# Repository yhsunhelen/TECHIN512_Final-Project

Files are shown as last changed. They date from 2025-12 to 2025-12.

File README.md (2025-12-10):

# Zombie Shooter – 90s-Style Handheld Reaction Game

A 90s-style handheld electronic game built with the Seeed Studio **XIAO ESP32C3** and **CircuitPython**.  
The game mixes fast reactions, motion aiming, sound input, a touch-shield, and zombies.

> Platform: XIAO ESP32C3 + CircuitPython  
> Display: SSD1306 128×64 OLED  
> Inputs: ADXL345 accelerometer, rotary encoder, trigger button, capacitive touch pad, sound sensor  
> Outputs: NeoPixel RGB LED, piezo buzzer, vibration motor  
> Power: LiPo battery + on/off switch

---

## How to Play

### 1. Power-On & Splash Screen

When the device is turned on:

- An animated story / splash screen is shown by `ui.show_boot_animation(display, btn)`.
- This splash animation plays **only on power-up**, not when restarting after Game Over.

After the splash, the game enters the **main menu**.

---

## Menus & Difficulty

The **rotary encoder** is used only outside of gameplay:

- Rotate to move between menu items.
- Press the encoder button to confirm.

Main menu (`menu.main_menu`):

- `PLAY` – start a new game.
- `SCORES` – view the high-score leaderboard.
- `SETTINGS` – change difficulty.

### Difficulty Settings

From `menu.difficulty_menu` the player can choose:

- `EASY`
- `NORMAL`
- `DIFFICULT`

The selected difficulty affects:

- How many zombies can be on screen at once.
- How quickly zombies spawn.
- How long each zombie stays alive before it disappears and may damage the player.

For each difficulty, `ZOMBIE_LIFETIME_TABLE` defines the lifetime for levels 1–10  
(shorter lifetimes at higher levels ⇒ harder).

---

## One-Time Tutorial (3 Parts)

The tutorial runs **once** after power-on, the first time the player chooses `PLAY`:

```python
tutorial_shown = False
...
if not tutorial_shown:
    show_tutorial(display)
    tutorial_shown = True
```

`show_tutorial(display)` contains 3 parts:

### Tutorial 1/3 – Shooting Z

- **Part 1-A (text)**: Explains that you tilt to move the `+` crosshair and press the button to shoot `Z`.
- **Part 1-B (practice)**:
  - A `+` crosshair and one `Z` appear on a clean screen.
  - The accelerometer (ADXL345) is read and filtered with an exponential moving average:

    ```python
    local_xf = local_alpha * x + (1 - local_alpha) * local_xf
    local_yf = local_alpha * y + (1 - local_alpha) * local_yf
    ```

  - Filtered X/Y are mapped to screen coordinates; the crosshair follows your tilt.
  - Pressing the trigger button checks if the crosshair is near the `Z`:
    - Close enough → `hit_effect()` (NeoPixel green, beep, vibration).
    - Miss → `miss_effect()` (NeoPixel red, different beep).

### Tutorial 2/3 – S & Sound Sensor

- **Part 2-A (text)**: Explains that when `S` appears you use **sound**, not aiming.
- **Part 2-B (practice)**:
  - A big `S` is shown on screen.
  - The digital sound sensor on D3 is read:
    - Quiet = 1, loud spike = 0
  - A transition `1 → 0` while the buzzer is not active triggers:
    - A beep and `hit_effect()` — simulating the destruction of `S` by a clap or shout.

### Tutorial 3/3 – T & Shield Touch

- **Part 3-A (text)**: Explains that when `T` appears, you touch the left pad to raise the shield.
- **Part 3-B (practice)**:
  - A simple scene with a `T` and text.
  - Touching the **left capacitive pad** (D2) long enough:
    - Calls `hit_effect()` and removes the T in the tutorial.
    - Demonstrates the “shield vs T” mechanic.

---

## Fingerprint Unlock (Touch Pad)

After the tutorial (if enabled by `FINGERPRINT_UNLOCK_ENABLED = True`),  
a “fingerprint unlock” screen appears before entering the real game:

```python
if FINGERPRINT_UNLOCK_ENABLED:
    fingerprint_unlock()
    display.root_group = main_group
```

`fingerprint_unlock()`:

- Shows text:

  > Know: put your finger  
  > on the left touch pad  
  > when it glows green,  
  > to unlock your weapon.

- Sets the NeoPixel to a **dim green** `(0, 80, 0)` while waiting.
- When the player touches the pad and holds it for `REQUIRED_HOLD = 0.5s`:
  - The text changes to:

    > Weapon unlocked!  
    > Welcome back,  
    > Zombie Hunter.  
    > Press BTN to start

  - NeoPixel changes to **bright green** `(0, 255, 0)`.
- The player presses the button to continue to the main game.

---

## Game Structure

### Levels & Timing

- Each run contains **10 levels** per difficulty:

  ```python
  MAX_LEVEL = 10
  GAME_DURATION = 10.0  # seconds per level
  ```

- Each level lasts exactly **10 seconds**.
- If the player is still alive when the level timer reaches 0:
  - If current level < 10 → advance to the next level.
  - If current level == 10 → the player has cleared all levels.

During gameplay the top of the OLED shows:

- `S:<score>` – current score
- `HP:<value>` – player health (max 3)
- `T:<seconds>` – remaining time in the current level

The bottom shows difficulty and level:

- `E L1`, `N L4`, `D L7`, etc.

### HP and Damage

- `MAX_HP = 3`
- When a zombie’s personal lifetime expires, `update_zombies()` checks the shield:
  - If shield **not** active → HP decreases by 1.
  - The zombie is removed.
- When HP decreases:
  - The HP label is updated.
  - `damage_effect()` plays: NeoPixel orange flash + vibration + low-pitch beep.
- If HP reaches 0:
  - `hp_reached_zero = True`
  - `running = False` → end of the game.

---

## Zombies & Player Moves

There are three zombie types:

- **Z** – standard zombie (shoot with crosshair + button)
- **S** – sound zombie (destroy with sound)
- **T** – shield zombie (destroy with touch shield)

Spawn logic (`spawn_zombie`) selects Z/S/T probabilities based on:

- Difficulty (`EASY`, `NORMAL`, `DIFFICULT`)
- Current level index

### In-Game Controls

1. **Aim with Tilt (ADXL345)**  
   - Crosshair `+` is always controlled by the accelerometer:

     ```python
     x_f = alpha * x + (1 - alpha) * x_f
     y_f = alpha * y + (1 - alpha) * y_f
     px = map_to_range(x_f, MIN_X, MAX_X, SCREEN_X_MIN, SCREEN_X_MAX)
     py = map_to_range(-y_f, MIN_Y, MAX_Y, SCREEN_Y_MIN, SCREEN_Y_MAX)
     ```

   - `alpha = 0.2` for smooth movement (low-pass filter).
   - Filtered values are mapped/clamped into the screen area and set as `crosshair.x` / `crosshair.y`.

2. **Shoot (Trigger Button on D9)**  
   - The trigger button is debounced by `update_button()`.
   - When pressed and **shield is not active** (`can_shoot = True`):
     - `fired_any_shot = True`
     - `muzzle_flash()` is called (NeoPixel white flash).
     - `find_hit_zombie(px, py)` tests if the crosshair overlaps a `Z`.
       - If a `Z` is found:
         - It is removed.
         - Score increments, label updated.
         - `hit_effect()` plays (green flashes, beep, vibration).
       - If nothing / `S` / `T` is hit:
         - `miss_effect()` plays (red flash, miss sound).

   - If the button is pressed while the shield is up (`can_shoot = False`):
     - The text area briefly shows `SHIELD UP!` and no shot is fired.

3. **Sound Move (Sound Sensor on D3, for S)**  
   - Each loop reads the digital sound sensor:
     - Quiet: `sound_sensor.value == 1`
     - Loud spike: `sound_sensor.value == 0`
   - A `1 → 0` edge is detected:

     ```python
     sound_edge = (sound_last_state and (not cur_sound))
     ```

   - If `sound_edge` and the buzzer is not playing:
     - One **S zombie** on screen is removed (loop breaks after the first).
     - Score increases and `hit_effect()` is called.

4. **Shield Move (Touch Pad on D2, for T)**  
   - `shield_active = bool(touch.value)`; when true:
     - `can_shoot = False` (cannot fire).
     - A loop walks through `zombies[:]`:
       - On the first alive `T` zombie:
         - It is removed.
         - Score increases.
         - `hit_effect()` plays.
         - Loop breaks → **one T per shield activation**.
   - When shield is active and a zombie lifetime ends:
     - The player does **not** lose HP (see `update_zombies`).

These four moves — **tilt to aim**, **shoot button**, **sound**, and **shield touch** — are the player’s actual actions.

---

## Scoring & Leaderboard

### Score

- Each destroyed zombie (Z/S/T) adds 1 point.
- Score label: `S:<value>` is updated whenever `game_score` changes.
- Final score is shown on the Game Over or victory/clear screen.

### Game Over & Clear

At the end of the `while running` loop:

- If the player survived all 10 levels → `cleared_all_levels = True`.
- If HP reached 0 → `hp_reached_zero = True`.

Then:

1. **Boss Easter Egg (Clear All Levels)**  
   If `cleared_all_levels` is `True`:

   ```python
   easter2.show_boss_easter(display, btn, buzzer)
   ```

   - Special animation of running through zombies and story text.
   - Buzzer sound effects during this sequence.

2. **No-Shot Easter Egg**  
   After the game:

   ```python
   if not fired_any_shot:
       easter.show_no_shot(display, btn, buzzer)
       display.root_group = main_group
       continue
   ```

   - If the player never fired a bullet in the whole run,  
     a “peaceful player / no bullet fired” easter egg screen is shown instead of the normal Game Over.

3. **Normal Game Over Screen**

   If the run was not a no-shot easter egg:

   ```python
   show_game_over(display, game_score, hp_reached_zero)
   ```

   - Displays:
     - `"YOU DIED"` if HP reached zero, or `"TIME UP"` otherwise.
     - `Score: <value>`
     - `BTN: CONTINUE`

4. **High Score Entry & Leaderboard**

   - Uses `score.py`:

     ```python
     if score.can_enter_leaderboard(game_score):
         player_name = NameInput.enter_name(display, encoder, btn, max_len=3)
         score.add_score(player_name, game_score)
     ```

   - `NameInput.enter_name` lets the player use the rotary encoder to select 3-character initials.
   - Scores are stored in `scores.json` on the internal flash (no SD card).
   - `show_leaderboard(display)` then shows the high score list:
     - Up to several entries with rank, initials, and score.
     - Encoder rotates to scroll if more entries exist.
     - Press button to go back to main menu.

The player can start a new game from the menu **without power-cycling**.

---

## NeoPixel Behavior

A single NeoPixel on **D10** is used for clear color-coded feedback:

- **Unlock Tutorial / Fingerprint Screen**
  - Dim green `(0, 80, 0)` while waiting for touch.
  - Bright green `(0, 255, 0)` when the weapon is successfully unlocked.

- **Shield Tutorial (Part 3 practice)**  
  - When the player successfully clears the T in the tutorial, a green flash + `hit_effect()` is used.

- **Muzzle Flash (Shooting) – `muzzle_flash()`**
  - Brief **white** `(255, 255, 255)` flash when the trigger is pressed.

- **Hit Effect – `hit_effect()`**
  - Two short **green** `(0, 255, 0)` flashes.
  - Vibration motor on D8 pulses.
  - A high-pitch beep plays.

- **Miss Effect – `miss_effect()`**
  - Single **red** `(255, 0, 0)` flash.
  - Medium-pitch miss beep.

- **Damage Effect – `damage_effect()`**
  - **Orange** `(255, 50, 0)` flash.
  - Vibration pulse and deeper tone.

After each effect, the pixel is set back to `(0, 0, 0)` (off).

> The NeoPixel uses multiple distinct colors (dim & bright green, white, red, orange),  
> which clearly satisfies the requirement to use more than one color.

---

## Audio & Vibration

### Buzzer (D7, PWM)

The buzzer is driven by `pwmio.PWMOut` on D7:

- `play_beep(freq, duration, volume)`:
  - Sets `buzzer_active = True` during playback to prevent the sound sensor from falsely triggering.
- **Game start sound**:

  ```python
  def game_start_sound():
      play_beep(500, 0.08)
      play_beep(750, 0.08)
      play_beep(1000, 0.12)
  ```

  Called at the beginning of each game.

- Different tones for:
  - Hit (`hit_effect`)
  - Miss (`miss_effect`)
  - Damage (`damage_effect`)
  - Tutorial confirmations and easter egg scenes.

### Vibration Motor (D8)

- Controlled by a digital output on D8:
  - Pulses during `hit_effect()` and `damage_effect()` to give haptic feedback.

---

## Sensors & Filtering

### ADXL345 Accelerometer

- Connected via I2C with the OLED.
- Used only for **aiming** the crosshair.
- The code uses an exponential moving average:

  ```python
  alpha = 0.2
  x_f = alpha * x + (1 - alpha) * x_f
  y_f = alpha * y + (1 - alpha) * y_f
  ```

- Then maps the smoothed values into a limited range `[MIN_X, MAX_X]` / `[MIN_Y, MAX_Y]` and finally into OLED pixel coordinates `[SCREEN_X_MIN, SCREEN_X_MAX]` / `[SCREEN_Y_MIN, SCREEN_Y_MAX]`.

This provides proper filtering for the accelerometer as required.

### Sound Sensor (D3)

- Digital input with pull-up:
  - Quiet: `1`
  - Loud spike: `0`
- A `1 → 0` transition triggers:
  - Tutorial Part 2 success.
  - In-game S-zombie kill (one `S` per edge).

### Touch Pad (D2)

- Digital input with pull-down.
- Used for:
  - Fingerprint unlock.
  - T-zombie shield move during gameplay.

### Trigger Button (D9) & Encoder

- Trigger button:
  - Debounced by `update_button()` for reliable edge detection.
- Rotary encoder:
  - Implemented by `RotaryEncoder` class in `rotary_encoder.py`.
  - Used for menus and name/initial selection.

---

## Files & Project Structure

Suggested repository structure:

```text
.
├── codfiles/
│   ├── code.py             # Main game loop, state machine, input handling
│   ├── ui.py               # Splash screen, story pages, UI screens
│   ├── menu.py             # Main menu and difficulty selection
│   ├── easter1.py          # First easter egg (optional/mini event)
│   ├── easter2.py          # Boss / major easter egg animation and story
│   ├── scores.py           # Scoring and high score storage (scores.json)
│   ├── name_input.py       # Rotary encoder-based name/initial input
│   ├── rotary_encoder.py   # Rotary encoder helper class / driver
│
├── lib/                    # CircuitPython libraries used by the game
│   ├── adafruit_display_text/
│   ├── adafruit_displayio_ssd1306.mpy
│   ├── adafruit_adxl34x.mpy
│   ├── i2cdisplaybus.mpy
│   ├── neopixel.mpy
│
├── Documentation/
│   ├── System Block Diagram.png  # system block diagram
│   └── Final Circuit Diagrams.pdf # wiring diagram / schematic
│
├── enclosure/
│   ├── 20251207_1.stl
│   ├── 20251207_2.stl
│
└── README.md

To run on the actual device, copy the contents of `code/` and `lib/` to the CIRCUITPY drive (with `code.py` at the root).

---
```
## Hardware & Enclosure Summary

- Seeed Studio **XIAO ESP32C3** microcontroller  
- **SSD1306 128×64 OLED** on I2C (shared with ADXL345)  
- **ADXL345 accelerometer** (I2C)  
- **Rotary encoder + push button** for menus & name input  
- **Trigger button** (D9) for shooting  
- **Capacitive touch pad** (D2) for shield/unlock  
- **Digital sound sensor** (D3) for S-zombie move  
- **NeoPixel RGB LED** (D10)  
- **Piezo buzzer** on D7 (PWM)  
- **Vibration motor** on D8  
- **LiPo battery** and **on/off switch**  
- All mounted on perfboard or a PCB using **female headers** so modules are removable.

The enclosure:

- Securely holds all electronics.
- Exposes:
  - USB-C port for the XIAO.
  - On/off switch.
  - OLED window.
  - Openings for trigger, encoder, and touch pad.
- Has a removable lid/side so the electronics can be accessed easily.
- Any 3D-printed parts are **not yellow**, following the project constraints.

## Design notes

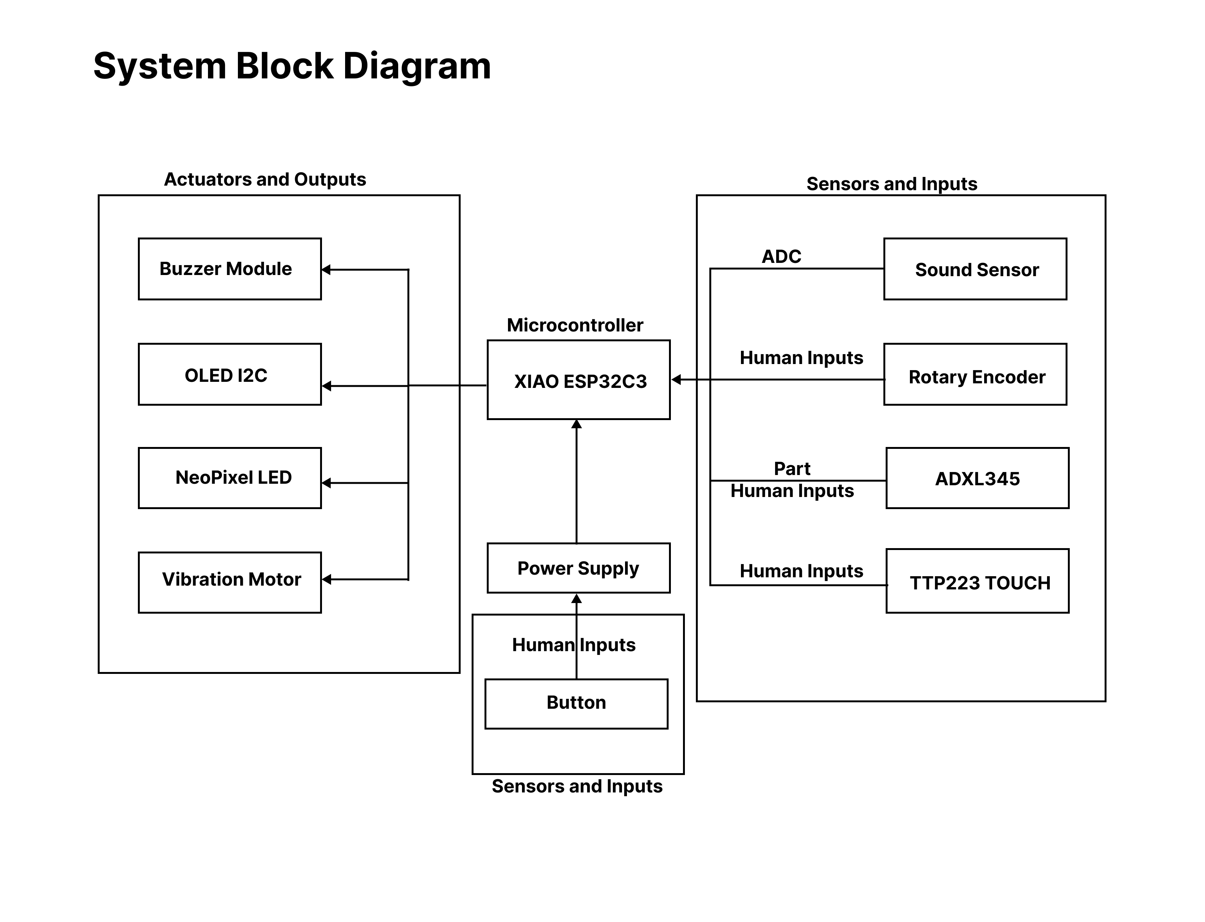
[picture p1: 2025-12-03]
Documentation/System Block Diagram.jpg

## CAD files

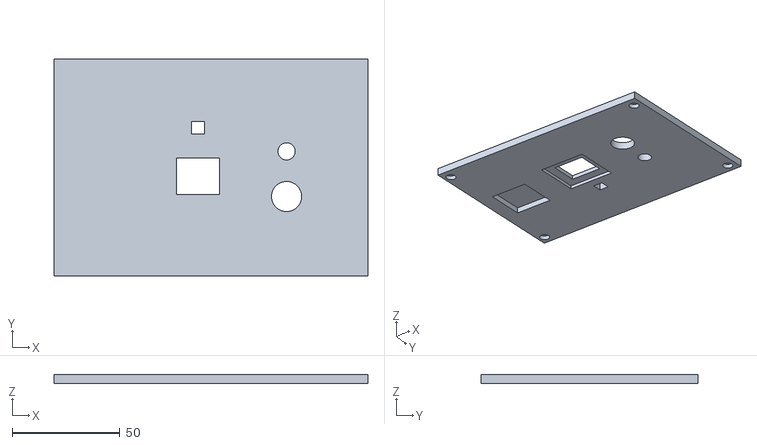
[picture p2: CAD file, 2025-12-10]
src/enclosure/20251207_1.stl
146.0 x 101.0 x 4.40

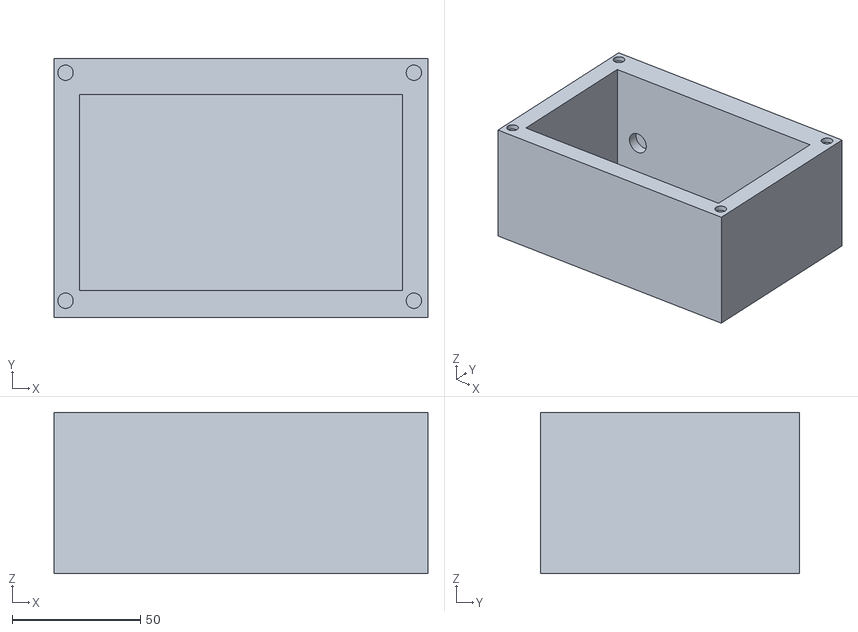
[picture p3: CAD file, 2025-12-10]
src/enclosure/20251207_2.stl
146.0 x 101.0 x 63.0

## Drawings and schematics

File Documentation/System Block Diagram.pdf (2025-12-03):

# System Block Diagram

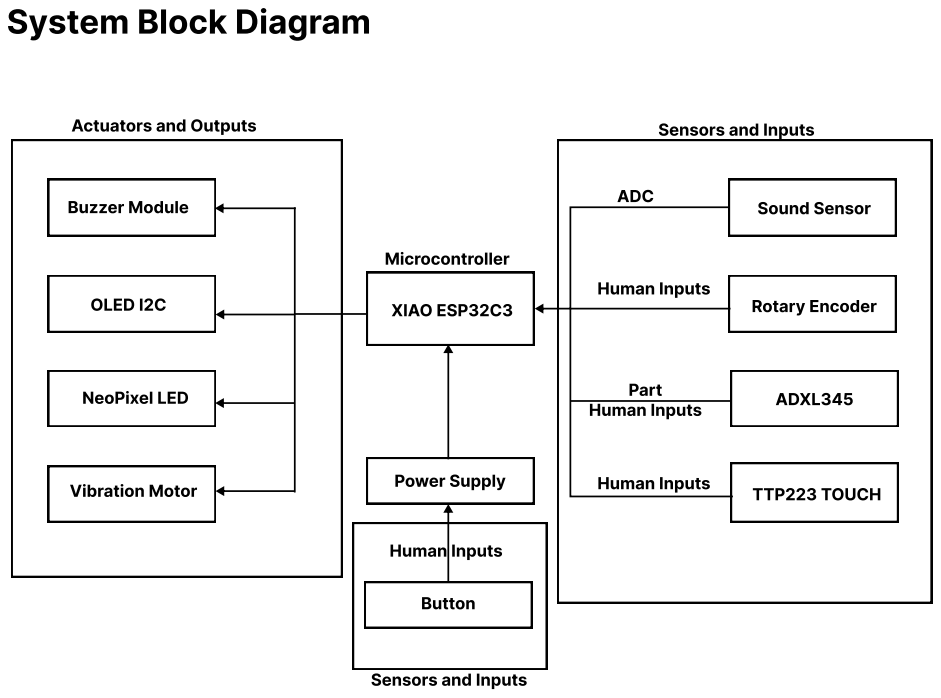
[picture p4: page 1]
Buzzer Module; Sound Sensor; OLED I2C; XIAO ESP32C3; Rotary Encoder; NeoPixel LED; ADXL345; Power Supply Vibration Motor; TTP223 TOUCH; Button; Actuators and Outputs; Sensors and Inputs; ADC; Microcontroller; Human Inputs; Part Human Inputs

Sensors and Inputs

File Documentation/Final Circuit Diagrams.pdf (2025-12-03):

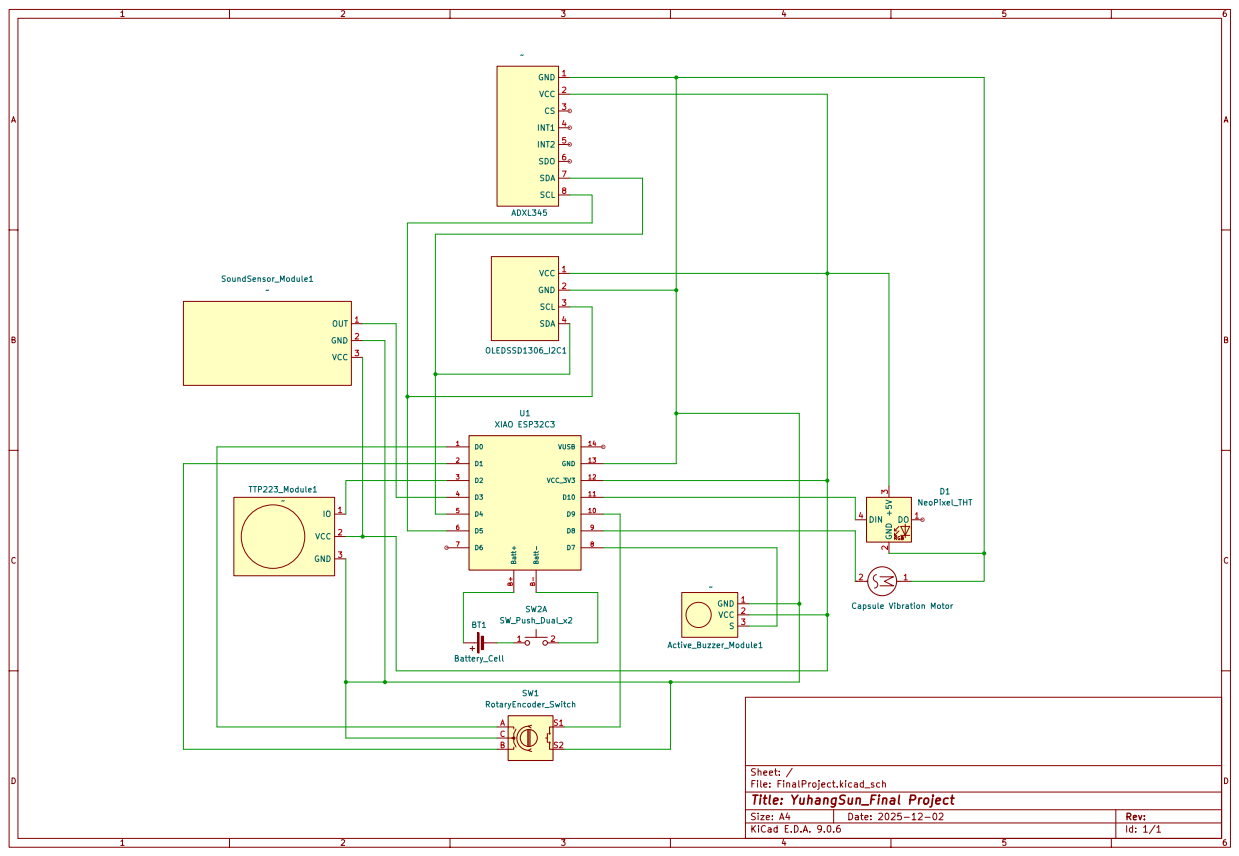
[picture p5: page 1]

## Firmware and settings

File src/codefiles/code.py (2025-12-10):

import time
import random

import board
import busio
import displayio
import terminalio
import digitalio
from adafruit_display_text import label
import i2cdisplaybus
import adafruit_displayio_ssd1306
import adafruit_adxl34x

import neopixel
import pwmio
import ui

from rotary_encoder import RotaryEncoder
import score          # leaderboard
import NameInput      # name input
import menu           # main menu & difficulty menu
import easter         # easter egg 1: no-shot
import easter2        # easter egg 2: clear all 10 levels


# ========== 0. CONSTANTS ==========

GAME_DURATION = 10.0       # seconds per level
MAX_HP = 3                 # player HP
MAX_LEVEL = 10             # 10 levels per difficulty
FLASH_WARNING_TIME = 3.0   # last seconds flashing before zombie disappears

# fingerprint unlock on/off
FINGERPRINT_UNLOCK_ENABLED = True

# tutorial only once per power-on
tutorial_shown = False

# 每难度、每一关僵尸停留时间（秒）——你可以自己改
ZOMBIE_LIFETIME_TABLE = {
    "EASY":      [8, 8, 7.5, 7.5, 7, 6.5, 6, 5.5, 5, 4.5],
    "NORMAL":    [7, 6.5, 6, 5.5, 5, 4.5, 4, 3.7, 3.4, 3],
    "DIFFICULT": [5, 4.5, 4, 3.5, 3, 2.8, 2.6, 2.4, 2.2, 2],
}


# ========== LEVEL CONFIG HELPER ==========

def get_level_config(difficulty, level_index):
    """
    Return parameters for a given difficulty + level:
      - max_on_screen: max zombies on screen (only depends on difficulty)
      - spawn_interval: spawn interval (seconds, only depends on difficulty)
      - zombie_lifetime: how long each zombie stays (seconds, depends on level)
      - hp_bonus: extra HP (here always 0, all zombies = 1 HP)
      - boss: True if this is the boss level (level 10)
    """

    # 同屏数量 & 刷新速度：只随难度变化
    if difficulty == "EASY":
        max_on_screen  = 3      # fewer zombies on screen
        spawn_interval = 2.5    # slower spawn
    elif difficulty == "NORMAL":
        max_on_screen  = 4
        spawn_interval = 1.8
    else:  # DIFFICULT
        max_on_screen  = 5      # more zombies
        spawn_interval = 1.2    # much faster spawn

    # 僵尸停留时间：由上面的表 + 当前关卡决定
    lifetime_list = ZOMBIE_LIFETIME_TABLE[difficulty]
    zombie_lifetime = lifetime_list[level_index - 1]  # level_index is 1-based

    # 所有僵尸 1 血，不再有多血僵尸
    hp_bonus = 0

    boss = (level_index == MAX_LEVEL)

    return {
        "max_on_screen": max_on_screen,
        "spawn_interval": spawn_interval,
        "zombie_lifetime": zombie_lifetime,
        "hp_bonus": hp_bonus,
        "boss": boss,
    }


# ========== 1. DISPLAY & I2C INIT ==========

displayio.release_displays()

i2c = busio.I2C(board.SCL, board.SDA)  # OLED + ADXL345 share I2C

display_bus = i2cdisplaybus.I2CDisplayBus(i2c, device_address=0x3C)
display = adafruit_displayio_ssd1306.SSD1306(display_bus, width=128, height=64)


# ========== 2. SENSORS / IO ==========

# ADXL345 accelerometer
accelerometer = adafruit_adxl34x.ADXL345(i2c)

# trigger button: D9 (pull-up, pressed = False)
btn = digitalio.DigitalInOut(board.D9)
btn.switch_to_input(pull=digitalio.Pull.UP)

# rotary encoder on D0, D1
encoder = RotaryEncoder(board.D0, board.D1, debounce_ms=3, pulses_per_detent=1)

# NeoPixel at D10
pixel = neopixel.NeoPixel(board.D10, 1, brightness=0.3, auto_write=False)

# vibration motor on D8
motor = digitalio.DigitalInOut(board.D8)
motor.switch_to_output(value=False)

# buzzer on D7 (PWM)
buzzer = pwmio.PWMOut(board.D7, duty_cycle=0, frequency=440, variable_frequency=True)

# buzzer state: True while buzzing (used to ignore sound sensor self-noise)
buzzer_active = False

# capacitive touch sensor (shield) on D2
touch = digitalio.DigitalInOut(board.D2)
touch.switch_to_input(pull=digitalio.Pull.DOWN)

# sound sensor on D3
# quiet = 1, sound = 0
sound_sensor = digitalio.DigitalInOut(board.D3)
sound_sensor.switch_to_input(pull=digitalio.Pull.UP)


# ========== 3. BUTTON DEBOUNCE ==========

last_state = btn.value
stable_state = btn.value
last_time = 0
debounce_delay = 0.02  # 20 ms

def update_button():
    """Return True when a new press edge is detected."""
    global last_state, stable_state, last_time
    now = time.monotonic()
    current_state = btn.value

    if current_state != last_state:
        last_time = now
        last_state = current_state

    pressed_event = False

    if (now - last_time) > debounce_delay:
        if stable_state != current_state:
            stable_state = current_state
            if not stable_state:   # stable_state False = pressed
                pressed_event = True

    return pressed_event


# ========== 4. LEADERBOARD & GAME OVER ==========

def show_leaderboard(display_obj):
    from score import load_scores

    records = load_scores()

    # no records
    if not records:
        group = displayio.Group()
        display_obj.root_group = group

        title = label.Label(terminalio.FONT, text="HIGH SCORES", x=0, y=8)
        group.append(title)

        msg = label.Label(terminalio.FONT, text="No records yet", x=0, y=30)
        group.append(msg)

        hint = label.Label(terminalio.FONT, text="BTN: BACK", x=0, y=56)
        group.append(hint)

        while True:
            if not btn.value:
                while not btn.value:
                    time.sleep(0.01)
                return
            time.sleep(0.01)

    PAGE_LINES = 3
    start_index = 0

    def clamp_start(idx):
        if len(records) <= PAGE_LINES:
            return 0
        if idx < 0:
            return 0
        max_start = len(records) - PAGE_LINES
        if idx > max_start:
            idx = max_start
        return idx

    def draw_page(start):
        group = displayio.Group()
        display_obj.root_group = group

        title = label.Label(terminalio.FONT, text="HIGH SCORES", x=0, y=8)
        group.append(title)

        y = 20
        end = min(start + PAGE_LINES, len(records))
        for i in range(start, end):
            item = records[i]
            line = f"{i+1}. {item['name']} {item['score']}"
            lbl = label.Label(terminalio.FONT, text=line, x=0, y=y)
            group.append(lbl)
            y += 12

        hint = label.Label(terminalio.FONT, text="ENC:SCROLL  BTN:BACK", x=0, y=56)
        group.append(hint)

    start_index = clamp_start(0)
    draw_page(start_index)

    encoder.update()
    last_pos = encoder.position

    while True:
        encoder.update()
        pos = encoder.position
        if pos != last_pos:
            delta = pos - last_pos
            last_pos = pos

            if delta > 0:
                start_index = clamp_start(start_index + 1)
                draw_page(start_index)
            elif delta < 0:
                start_index = clamp_start(start_index - 1)
                draw_page(start_index)

        if not btn.value:
            time.sleep(0.05)
            if not btn.value:
                while not btn.value:
                    time.sleep(0.01)
                return

        time.sleep(0.01)


def show_game_over(display_obj, score_value, hp_reached_zero):
    group = displayio.Group()
    display_obj.root_group = group

    text = "YOU DIED" if hp_reached_zero else "TIME UP"

    go_label = label.Label(terminalio.FONT, text=text, x=20, y=20)
    group.append(go_label)

    score_lbl = label.Label(terminalio.FONT, text=f"Score: {score_value}", x=20, y=35)
    group.append(score_lbl)

    hint_label = label.Label(terminalio.FONT, text="BTN: CONTINUE", x=5, y=56)
    group.append(hint_label)

    while True:
        if not btn.value:
            while not btn.value:
                time.sleep(0.01)
            break
        time.sleep(0.01)


def show_easter_egg_no_shot(display_obj):
    group = displayio.Group()
    display_obj.root_group = group

    title = label.Label(terminalio.FONT, text="SECRET MODE!", x=5, y=15)
    group.append(title)

    line1 = label.Label(terminalio.FONT, text="No bullet fired.", x=5, y=30)
    group.append(line1)

    line2 = label.Label(terminalio.FONT, text="Peaceful player :)", x=5, y=42)
    group.append(line2)

    hint = label.Label(terminalio.FONT, text="BTN: BACK TO MENU", x=0, y=56)
    group.append(hint)

    while True:
        if not btn.value:
            while not btn.value:
                time.sleep(0.01)
            break
        time.sleep(0.01)


# ========== 5. FINGERPRINT UNLOCK (OPTIONAL) ==========

def fingerprint_unlock():
    """
    Simulated fingerprint unlock: ask player to touch the left capacitive pad.
    """
    group = displayio.Group()
    display.root_group = group

    line1 = label.Label(terminalio.FONT,
                        text="Know: put your finger",
                        x=0, y=15)
    line2 = label.Label(terminalio.FONT,
                        text="on the left touch pad",
                        x=0, y=27)
    line3 = label.Label(terminalio.FONT,
                        text="when it glows green,",
                        x=0, y=39)
    line4 = label.Label(terminalio.FONT,
                        text="to unlock your weapon.",
                        x=0, y=51)
    group.append(line1)
    group.append(line2)
    group.append(line3)
    group.append(line4)

    pixel[0] = (0, 80, 0)
    pixel.show()

    touched_start = None
    REQUIRED_HOLD = 0.5  # seconds

    while True:
        if touch.value:
            if touched_start is None:
                touched_start = time.monotonic()
            else:
                if time.monotonic() - touched_start >= REQUIRED_HOLD:
                    line1.text = "Weapon unlocked!"
                    line2.text = "Welcome back,"
                    line3.text = "Zombie Hunter."
                    line4.text = "Press BTN to start"
                    pixel[0] = (0, 255, 0)
                    pixel.show()
                    break
        else:
            touched_start = None

        time.sleep(0.02)

    while True:
        if not btn.value:
            while not btn.value:
                time.sleep(0.01)
            break

    pixel[0] = (0, 0, 0)
    pixel.show()


# ========== 6. BOOT ANIMATION ==========

ui.show_boot_animation(display, btn, buzzer)


# ========== 7. GAME UI GROUP (ONLY ONCE) ==========

main_group = displayio.Group()

score_label = label.Label(terminalio.FONT, text="S:0", x=0, y=8)
hp_label    = label.Label(terminalio.FONT, text=f"HP:{MAX_HP}", x=44, y=8)
timer_label = label.Label(terminalio.FONT, text="T:10", x=88, y=8)

crosshair = label.Label(terminalio.FONT, text="+", x=64, y=36)

zombies_group = displayio.Group()

state_label = label.Label(terminalio.FONT, text="N L1", x=0, y=54)
info        = label.Label(terminalio.FONT, text="",   x=0, y=56)

main_group.append(score_label)
main_group.append(hp_label)
main_group.append(timer_label)
main_group.append(crosshair)
main_group.append(zombies_group)
main_group.append(state_label)
main_group.append(info)

display.root_group = main_group


# ========== 8. MAPPING & ZOMBIE MANAGEMENT ==========

alpha = 0.2
x_f = 0.0
y_f = 0.0

MIN_X = -6.0
MAX_X =  6.0
MIN_Y = -6.0
MAX_Y =  6.0

SCREEN_X_MIN = 0
SCREEN_X_MAX = 127
SCREEN_Y_MIN = 18
SCREEN_Y_MAX = 48

def map_to_range(value, in_min, in_max, out_min, out_max):
    if value < in_min:
        value = in_min
    if value > in_max:
        value = in_max
    span_in = in_max - in_min
    ratio = (value - in_min) / span_in
    return int(out_min + ratio * (out_max - out_min))


zombies = []
last_spawn_time = 0.0


def spawn_zombie(level_cfg, level_index):
    global zombies_group

    # type: Z / S / T
    r = random.random()

    if level_cfg["boss"]:
        # boss level: 10% Z, 40% S, 50% T
        if r < 0.10:
            z_type = "Z"
        elif r < 0.50:
            z_type = "S"
        else:
            z_type = "T"
    else:
        if level_index == 1:
            z_type = "Z"  # level 1: only Z
        elif level_index <= 3:
            # level 2–3: 80% Z, 10% S, 10% T
            if r < 0.80:
                z_type = "Z"
            elif r < 0.90:
                z_type = "S"
            else:
                z_type = "T"
        else:
            # level 4–9: 60% Z, 20% S, 20% T
            if r < 0.60:
                z_type = "Z"
            elif r < 0.80:
                z_type = "S"
            else:
                z_type = "T"

    # 所有僵尸 1 血
    if z_type == "Z":
        glyph = "Z"
    elif z_type == "S":
        glyph = "S"
    else:  # "T"
        glyph = "T"

    hp = 1

    zx = random.randint(SCREEN_X_MIN + 5, SCREEN_X_MAX - 5)
    zy = random.randint(SCREEN_Y_MIN + 5, SCREEN_Y_MAX - 5)

    z_label = label.Label(terminalio.FONT, text=glyph, x=zx, y=zy)
    zombies_group.append(z_label)

    zombie = {
        "label": z_label,
        "x": zx,
        "y": zy,
        "spawn_time": time.monotonic(),
        "lifetime": level_cfg["zombie_lifetime"],
        "type": z_type,
        "hp": hp,
        "max_hp": hp,
        "dead": False,
    }
    zombies.append(zombie)


def find_hit_zombie(px, py):
    """Return the first zombie hit by crosshair (only Z is killable by shooting)."""
    for z in zombies:
        if z["dead"]:
            continue
        dx = abs(px - z["x"])
        dy = abs(py - z["y"])
        if dx <= 6 and dy <= 8:
            return z
    return None


def remove_zombie(z):
    if z not in zombies:
        return
    z["dead"] = True
    try:
        zombies_group.remove(z["label"])
    except ValueError:
        pass
    zombies.remove(z)


def update_zombies(now, shield_active, player_hp, level_cfg):
    """
    Update flashing / disappearing.
    When a zombie lifetime ends:
      - if shield is NOT active -> player takes damage
      - then zombie is removed
    """
    for z in zombies[:]:
        if z["dead"]:
            continue

        age = now - z["spawn_time"]
        lifetime = z["lifetime"]
        lbl = z["label"]

        if age >= lifetime:
            if not shield_active:
                player_hp -= 1
            remove_zombie(z)
            continue

        warn_time = min(FLASH_WARNING_TIME, lifetime)
        if age >= lifetime - warn_time:
            flash_phase = int((age - (lifetime - warn_time)) * 6)
            lbl.hidden = (flash_phase % 2 == 1)
        else:
            lbl.hidden = False

    return player_hp


# ========== 9. EFFECTS & UI HELPERS ==========

def muzzle_flash():
    pixel[0] = (255, 255, 255)
    pixel.show()
    time.sleep(0.03)
    pixel[0] = (0, 0, 0)
    pixel.show()


def play_beep(freq=800, duration=0.1, volume=0.3):
    global buzzer_active
    buzzer_active = True
    buzzer.frequency = int(freq)
    buzzer.duty_cycle = int(65535 * volume)
    time.sleep(duration)
    buzzer.duty_cycle = 0
    buzzer_active = False


def hit_effect():
    for _ in range(2):
        pixel[0] = (0, 255, 0)
        pixel.show()
        motor.value = True
        play_beep(freq=1200, duration=0.05, volume=0.4)
        motor.value = False
        pixel[0] = (0, 0, 0)
        pixel.show()
        time.sleep(0.05)


def miss_effect():
    pixel[0] = (255, 0, 0)
    pixel.show()
    play_beep(freq=300, duration=0.1, volume=0.3)
    pixel[0] = (0, 0, 0)
    pixel.show()


def damage_effect():
    pixel[0] = (255, 50, 0)
    pixel.show()
    motor.value = True
    play_beep(freq=200, duration=0.15, volume=0.4)
    motor.value = False
    pixel[0] = (0, 0, 0)
    pixel.show()


def game_start_sound():
    play_beep(freq=500, duration=0.08, volume=0.3)
    play_beep(freq=750, duration=0.08, volume=0.3)
    play_beep(freq=1000, duration=0.15, volume=0.35)


def update_hp_display(hp):
    hp_label.text = f"HP:{hp}"


def update_state_display(difficulty, level_index):
    diff_char = difficulty[0]   # E / N / D
    state_label.text = f"{diff_char} L{level_index}"


def show_level_banner(level_index):
    """Full-screen 'LEVEL X' banner in the center."""
    group = displayio.Group()
    display.root_group = group

    text = f"LEVEL {level_index}"
    # 简单水平居中估算：每个字符大约 6 像素宽
    x = max(0, (128 - len(text) * 6) // 2)
    y = 32

    lbl = label.Label(terminalio.FONT, text=text, x=x, y=y)
    group.append(lbl)

    time.sleep(1.2)  # 显示约 1.2 秒

    display.root_group = main_group


def wait_for_button_release_press():
    """Helper: wait for a full press cycle."""
    # 等待松手
    while not btn.value:
        time.sleep(0.01)
    # 等待按下
    while True:
        if not btn.value:
            while not btn.value:
                time.sleep(0.01)
            break
        time.sleep(0.01)


# ========== 10. TUTORIAL (ONLY FIRST PLAY) ==========

def show_tutorial(display_obj):
    """
    Intro tutorial shown once after power-on:
      Part 1: Text -> practice shoot Z
      Part 2: Text -> practice kill S by sound
      Part 3: Text -> practice T + touch/shield
    """

    # --- Part 1-A: text only ---
    g1_text = displayio.Group()
    display_obj.root_group = g1_text

    title = label.Label(terminalio.FONT, text="Tutorial 1/3", x=0, y=8)
    line1 = label.Label(terminalio.FONT, text="Tilt to move +", x=0, y=22)
    line2 = label.Label(terminalio.FONT, text="Aim + on Z", x=0, y=34)
    line3 = label.Label(terminalio.FONT, text="Press BTN to shoot", x=0, y=46)
    hint = label.Label(terminalio.FONT, text="BTN: NEXT", x=0, y=58)

    g1_text.append(title)
    g1_text.append(line1)
    g1_text.append(line2)
    g1_text.append(line3)
    g1_text.append(hint)

    wait_for_button_release_press()

    # --- Part 1-B: practice shooting Z on empty page ---
    g1 = displayio.Group()
    display_obj.root_group = g1

    tut_z = label.Label(terminalio.FONT, text="Z", x=64, y=36)
    g1.append(tut_z)

    tut_cross = label.Label(terminalio.FONT, text="+", x=64, y=20)
    g1.append(tut_cross)

    hit_ok = False
    local_xf = 0.0
    local_yf = 0.0
    local_alpha = 0.2

    while not hit_ok:
        try:
            x, y, z = accelerometer.acceleration
        except OSError:
            x = y = z = 0.0

        local_xf = local_alpha * x + (1 - local_alpha) * local_xf
        local_yf = local_alpha * y + (1 - local_alpha) * local_yf

        px = map_to_range(local_xf, MIN_X, MAX_X, SCREEN_X_MIN, SCREEN_X_MAX)
        py = map_to_range(-local_yf, MIN_Y, MAX_Y, SCREEN_Y_MIN, SCREEN_Y_MAX)

        tut_cross.x = px
        tut_cross.y = py

        if update_button():
            dx = abs(tut_cross.x - tut_z.x)
            dy = abs(tut_cross.y - tut_z.y)
            if dx <= 6 and dy <= 8:
                hit_ok = True
                hit_effect()
            else:
                miss_effect()

        time.sleep(0.02)

    time.sleep(0.6)

    # --- Part 2-A: text only for S ---
    g2_text = displayio.Group()
    display_obj.root_group = g2_text

    s_title = label.Label(terminalio.FONT, text="Tutorial 2/3", x=0, y=8)
    s1 = label.Label(terminalio.FONT, text="When S appears,", x=0, y=22)
    s2 = label.Label(terminalio.FONT, text="no need to aim.", x=0, y=34)
    s3 = label.Label(terminalio.FONT, text="Make a loud sound", x=0, y=46)
    s_hint = label.Label(terminalio.FONT, text="BTN: NEXT", x=0, y=58)

    g2_text.append(s_title)
    g2_text.append(s1)
    g2_text.append(s2)
    g2_text.append(s3)
    g2_text.append(s_hint)

    wait_for_button_release_press()

    # --- Part 2-B: practice S on clean page ---
    g2 = displayio.Group()
    display_obj.root_group = g2

    s_demo = label.Label(terminalio.FONT, text="S", x=64, y=36)
    g2.append(s_demo)

    last_state = sound_sensor.value  # quiet = 1
    triggered = False

    while not triggered:
        cur = sound_sensor.value
        if last_state and (not cur) and (not buzzer_active):
            triggered = True
            play_beep(freq=900, duration=0.08, volume=0.4)
            hit_effect()
        last_state = cur
        time.sleep(0.01)

    time.sleep(0.6)

    # --- Part 3-A: text only for T ---
    g3_text = displayio.Group()
    display_obj.root_group = g3_text

    t_title = label.Label(terminalio.FONT, text="Tutorial 3/3", x=0, y=8)
    t1 = label.Label(terminalio.FONT, text="When T appears,", x=0, y=22)
    t2 = label.Label(terminalio.FONT, text="touch left pad to", x=0, y=34)
    t3 = label.Label(terminalio.FONT, text="raise shield", x=0, y=46)
    t_hint = label.Label(terminalio.FONT, text="BTN: NEXT", x=0, y=58)

    g3_text.append(t_title)
    g3_text.append(t1)
    g3_text.append(t2)
    g3_text.append(t3)
    g3_text.append(t_hint)

    wait_for_button_release_press()

    # --- Part 3-B: practice T on clean page ---
    g3 = displayio.Group()
    display_obj.root_group = g3

    t_demo = label.Label(terminalio.FONT, text="T", x=64, y=36)
    g3.append(t_demo)

    hold_start = None
    HOLD_TIME = 0.5
    unlocked = False

    while not unlocked:
        if touch.value:
            if hold_start is None:
                hold_start = time.monotonic()
            else:
                if time.monotonic() - hold_start >= HOLD_TIME:
                    unlocked = True
                    pixel[0] = (0, 150, 0)
                    pixel.show()
                    hit_effect()
        else:
            hold_start = None
        time.sleep(0.02)

    time.sleep(0.6)

    pixel[0] = (0, 0, 0)
    pixel.show()
    display_obj.root_group = main_group


# ========== 11. MAIN GAME LOOP ==========

current_difficulty = "NORMAL"
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

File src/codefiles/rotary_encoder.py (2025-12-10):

import time
import digitalio

class RotaryEncoder:
    """
    RotaryEncoder(pin_a, pin_b, *, pull=digitalio.Pull.UP, debounce_ms=3, pulses_per_detent=4)

    - pin_a, pin_b: board pin objects (e.g. board.D1, board.D0)
    - debounce_ms: stable time (ms) before accepting a new state 
    - pulses_per_detent: number of encoder edges per visible detent. Set to 1 if you want
      raw edges, or to 4 for many encoders so 1 detent == 1 step.
    """

    # Quadrature Table
    _TRANSITIONS = {
        0b0001:  1,  
        0b0011:  1,  
        0b0111:  1,  
        0b0100: -1,  
        0b1110:  1,  
        0b1101: -1,  
        0b1000:  1,  
        0b1011: -1,  
        }

    def __init__(self, pin_a, pin_b, *, pull=digitalio.Pull.UP, debounce_ms=3, pulses_per_detent=3):
        self._a = digitalio.DigitalInOut(pin_a)
        self._a.switch_to_input(pull=pull)
        self._b = digitalio.DigitalInOut(pin_b)
        self._b.switch_to_input(pull=pull)

        self._debounce_ms = max(1, int(debounce_ms))
        self._pulses_per_detent = max(1, int(pulses_per_detent))

        self._last_raw = (self._a.value, self._b.value)
        self._last_stable = self._last_raw
        self._last_change_time = time.monotonic() * 1000.0 

        self._last_q = (1 if self._last_stable[0] else 0) << 1 | (1 if self._last_stable[1] else 0)

        self._position_raw = 0
        self._position = 0
        self._delta_accum = 0

    @staticmethod
    def _pack(state):
        
        return (1 if state[0] else 0) << 1 | (1 if state[1] else 0)

    def _read_raw(self):
        return (self._a.value, self._b.value)

    def update(self):
        now = time.monotonic() * 1000.0
        raw = self._read_raw()
        if raw != self._last_raw:
            
            self._last_raw = raw
            self._last_change_time = now
            return False

        if raw != self._last_stable and (now - self._last_change_time) >= self._debounce_ms:
            prev_q = self._last_q
            self._last_stable = raw
            curr_q = self._pack(raw)
            self._last_q = curr_q

            key = (prev_q << 2) | curr_q
            move = self._TRANSITIONS.get(key, 0)

 
            if move == 0:
                diff = (curr_q - prev_q) % 4
                if diff == 1:
                    move = 1
                elif diff == 3:
                    move = -1
                elif diff == 2:
                    move = 2 if ( (curr_q - prev_q) > 0 ) else -2

            if move != 0:
                self._position_raw += int(move)

                new_pos = self._position_raw // self._pulses_per_detent
                if new_pos != self._position:
                    delta = new_pos - self._position
                    self._position = new_pos
                    self._delta_accum += delta
                    return True
        return False

    @property
    def position(self):
        return self._position

    @property
    def position_raw(self):
        return self._position_raw

    def get_delta(self):
        d = self._delta_accum
        self._delta_accum = 0
        return d

    def reset(self, *, to_detent=None):
        if to_detent is None:
            self._position_raw = 0
            self._position = 0
        else:
            self._position = int(to_detent)
            self._position_raw = self._position * self._pulses_per_detent
        self._delta_accum = 0

    

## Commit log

2025-12-03 20251202_TECHIN512_Final Project Take Home Assignment 4_add Diagrams and blank README
    [FinalProject_Circuit Diagrams.kicad_sch]
2025-12-10 README and codefiles
    [20251207_1.stl, 20251207_2.stl]
2025-12-10 change file name and structure
    [FinalProject_Circuit Diagrams.kicad_sch]
